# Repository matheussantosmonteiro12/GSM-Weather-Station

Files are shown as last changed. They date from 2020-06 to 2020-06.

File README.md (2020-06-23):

# GSM-Weather-Station
Estação meteorológica que mede microclimas e envia esses dados via GSM. 
## Resumo: 
Este projeto propõe uma rede de monitoramento climático utilizando estações meteorológicas autonomas, que transmitem os dados coletados atraves rede GSM (Global System for Mobile Communications), para um Middleware IoT, responsável por fazer a persistencia dos dados e fornecer informações sobre o clima para as diversas aplicações, focadas em ajudar os usuários no planejamento da rotina diária.
## Programas Necessários:
-**IDE arduino**, https://www.arduino.cc/en/Main/Software.

-**Cura Software** ou **Slic3r**.

## Companentes necessários:
- 1 Módulo A6 Gsm/Gprs.

- 1 Arduino mega.

- 1 Módulo sensor de chuva.

- 1 Módulo sensor de luminosidade de luz LDR.

- 1 Sensor de umidade e temperatura DHT 11.

- 1 Atiny 85.

- 1 Regulador de Tensão 7805 5V.

- 1 Relé nec 5V.

- 1 Módulo carregador tp4056.

- 3 Painel Placa Solar 12v 1.50w Carregador Ecologico 9v.

- 1 Modulo Conversor Tensão Dc/dc Step Up.

## Arquitetura da solução proposta:
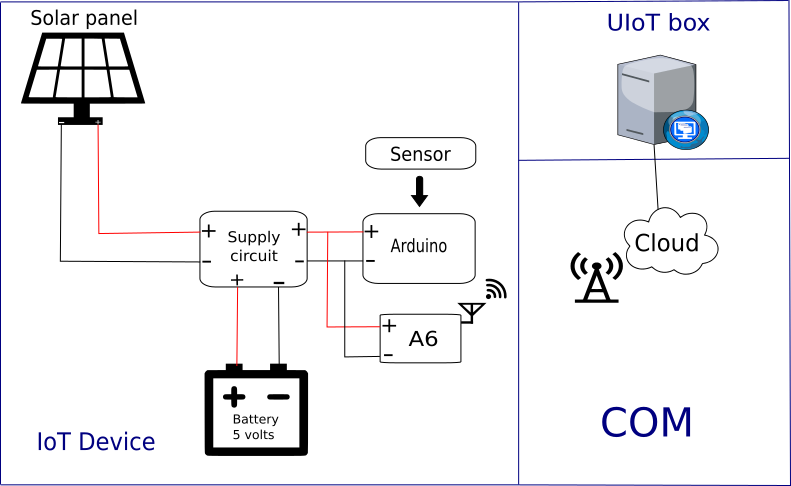
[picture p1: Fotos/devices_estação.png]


## Circuito de alimentação:
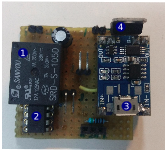
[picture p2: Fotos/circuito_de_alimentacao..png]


**1) Relé, 2) Microcontrolador, 3) Carregador de bateria, 4) Regulador de tensão.**

## Circuito principal:
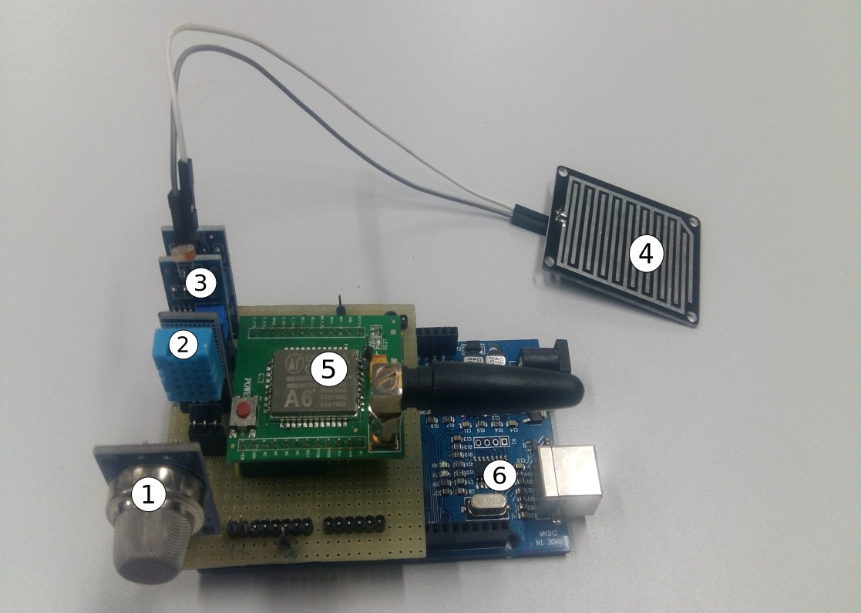
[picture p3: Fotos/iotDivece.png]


**1) Sensor de gás, 2) Sensor de temperatura e umidade, 3) Sensor de luminosidade, 4) Sensor de chuva, 5) A6 GSM/GPRS, 6) Microcontrolador.**

## Versão final da estação:
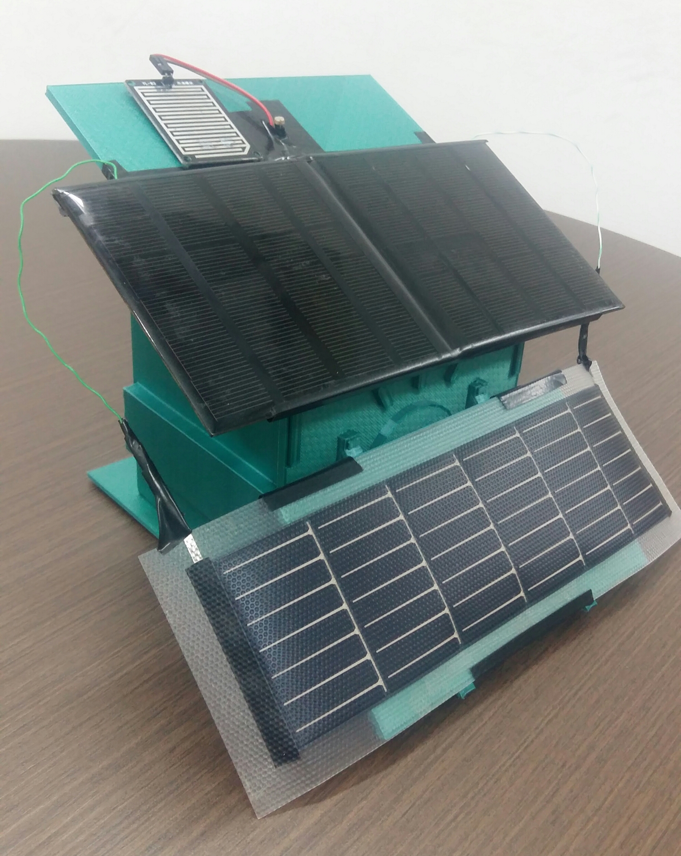
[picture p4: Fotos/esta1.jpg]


#### Link do Artigo sobre esse projeto:
https://ieeexplore.ieee.org/abstract/document/8896242

#### OBS:
Para qualquer outras duvidas me mande um email no matheus.monteiro@uiot.org.

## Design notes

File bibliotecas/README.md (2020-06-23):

# UIoT Devices

This librarys aim is to enable users to create *Clients* and *Services* that follow UIoT's Ontology of sending and managing message flows in Arduino devices.

All the protocols included as a means of communication in this library follow the same principles:

 1. Create a *Device*
 2. Create a *Service*
 3. Send *Data*

<!-- The documentation of the Ontology followed by this library can be found at @@link-ontologia -->

The supported protocols by supported devices are displayed in the following table.

<table>
<tr>
    <th>Device</th>
    <th>Protocol</th>
    <th>Example</th>
  </tr>
  <tr>
    <td rowspan = 1 ><a href="https://github.com/uiot/client_libraries/tree/master/UIoTDevices">Arduino</a></td>
    <td>HTTP</td>
      <td><a href="https://github.com/uiot/client_libraries/tree/master/UIoTDevices/examples/httpExampleArduino">httpExampleArduino</a></td>
  </tr>
  <tr>
    <td rowspan = 1><a href="https://github.com/uiot/client_libraries/tree/master/UIoTDevices_esp8266">Esp8266</a></td>
    <td>HTTP</td>
      <td><a href="https://github.com/uiot/client_libraries/tree/master/UIoTDevices_esp8266/examples/httpExampleEsp8266">httpExampleEsp8266</a></td>
  </tr>
  </table>

Examples can also be found in the table above, with a full code that uses the corresponding library. All examples can be found int the examples folder.

# Arduino

# HTTP

  The HTTP library depends on the following libraries:

  * EEPROM.h
  * Ethernet.h

  So, they must be installed in the users environment. The Ethernet library was used and tested to the WizNet 5100 Ethernet Shield.

  ## Creating a Device

  A *Device* is an object of the UHttp class that represents the hardware whose means of communication protocol is the HTTP.

  To create a device using UHttp library you must create an instance of it, initialize it and, finally, set a server to send data to, as demonstrated below

  ```c++
  UHttp device;
  (...)
  device.init();
  device.set_server(SERVER_STRING);
  ```

## Creating a Service

  A *Service* in an object of the Service class that represents a task witch a *Device* has.

  To create a service using UHttp library you must create an instance of it and set a value from the [*UHttp.create_service*](#create_service) method as demonstrated below

  ```c++
  Service service1;
  (...)
  device.create_service(number, name, unit, numeric, parameter);
  ```

## Sending Data

  To send data to the specified server, you must use the [*UHttp.send_data*](#send_data) method as demonstrated below

  ```c++
    device.send_data(service1, ptr , tam, 0);
  ```

## Methods

### set_server

```c++
void UHttp::set_server(const char *server)
```

| Parameter | Type | Description | Obligatory |
|-|-|-|-|
| server | char* | array of characters that contains the servers domain or IP[1] | :heavy_check_mark:

[1]The servers port is set to 8000 byt default, to change it you must define your a variable called *HTTP_PORT* in your code.

### create_service

```c++
int BaseProtocol::create_service(int number, const char *name, String unit, bool numeric, String parameter)
```

| Parameter | Type | Description | Obligatory |
|-|-|-|-|
| number | int | Number to be attributed to the Service object that is beeing created | :heavy_check_mark:
| name | char* | Array of characters that mounts the name of the Service object that is beein created| :heavy_check_mark:
| unit | String | String that contais the unit of the value that is produced by the Service object that is beeing createed | :heavy_check_mark:
| numeric | bool | Value that indicates if the data produced by the service is of a numeric type or not | :heavy_check_mark:
| parameter | String | Value that indicates the parameters of the Service object that is beeing created | :heavy_check_mark:

### send_data

```c++
    bool BaseProtocol::send_data(Service service, float *data, int array_size, int sensitive=0)
```

| Parameter | Type | Description | Obligatory |
|-|-|-|-|
| service | Service | Service object with the *services* characteristics | :heavy_check_mark:
| data | float* | Array of float values corresponding to the data produced from the service| :heavy_check_mark:
| array_size | int | number of values in the data array | :heavy_check_mark:
| sensitive | int | value that indicates if the data is sensitive or not, that is, if the data must bypass the gateways buffer (default value is 0 - not sensitive)| :x:

```c++
    bool BaseProtocol::send_data(Service service, char *char_data, int sensitive=0)
```

| Parameter | Type | Description | Obligatory |
|-|-|-|-|
| service | Service | Service object with the *services* characteristics | :heavy_check_mark:
| char_data | float* | Array of characters with the value corresponding to the data produced from the service| :heavy_check_mark:
| sensitive | int | value that indicates if the data is sensitive or not, that is, if the data must bypass the gateways buffer (default value is 0 - not sensitive)| :x:

<!-- TODO# Serial -->

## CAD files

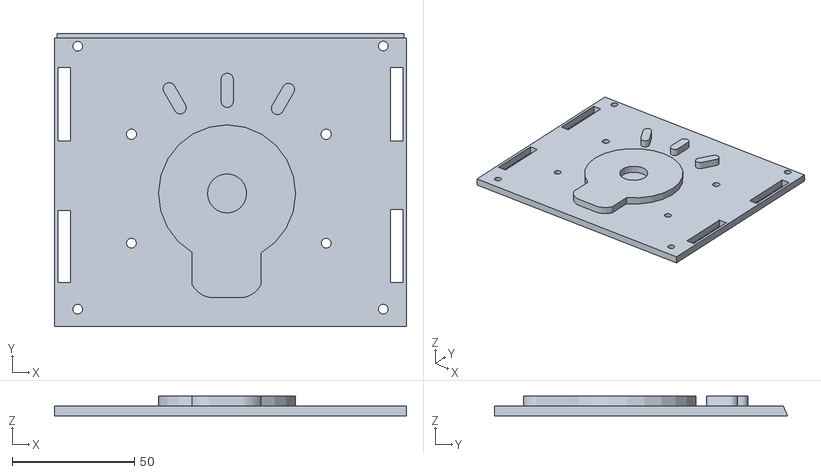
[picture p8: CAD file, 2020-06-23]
Modelagem da caixa em 3D/2.Tampa_do_lado_fixed.stl
144.0 x 120.0 x 8.00

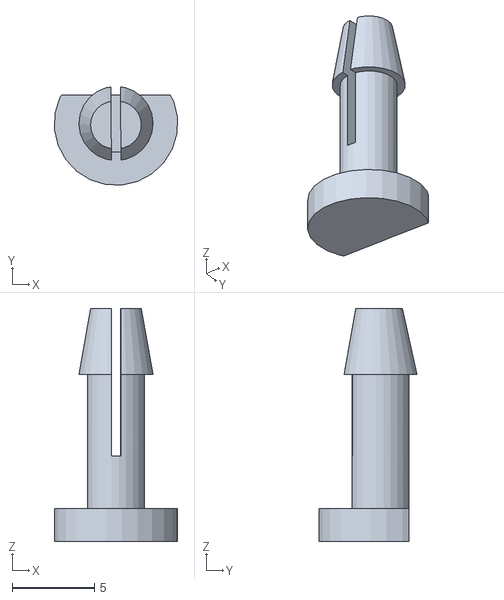
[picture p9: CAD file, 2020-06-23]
Modelagem da caixa em 3D/6.Clip_8x4_mm_uiot_fixed.stl
7.46 x 5.95 x 14.1

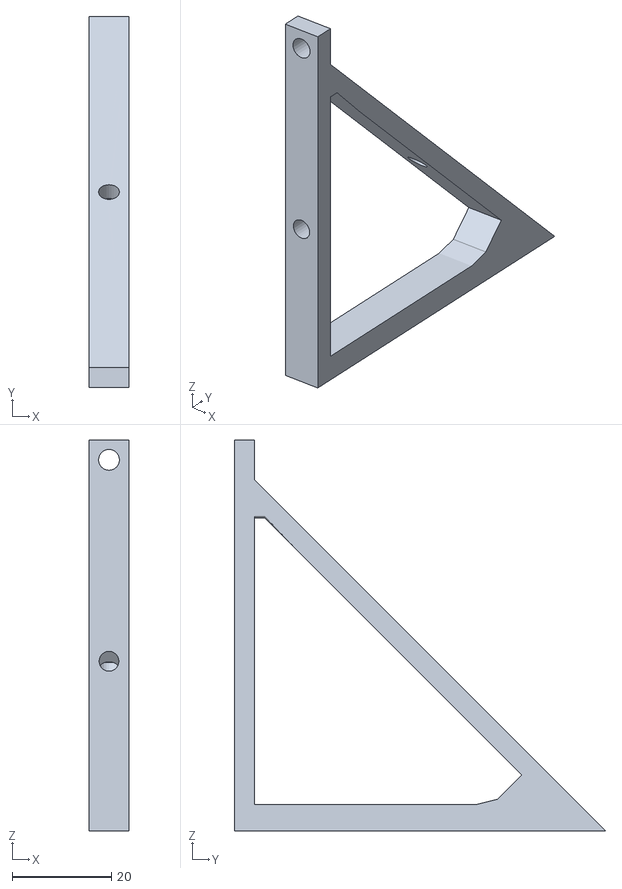
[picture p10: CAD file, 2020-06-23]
Modelagem da caixa em 3D/4.Suporte_para_placa_solar_fixed.stl
8.00 x 74.7 x 78.7

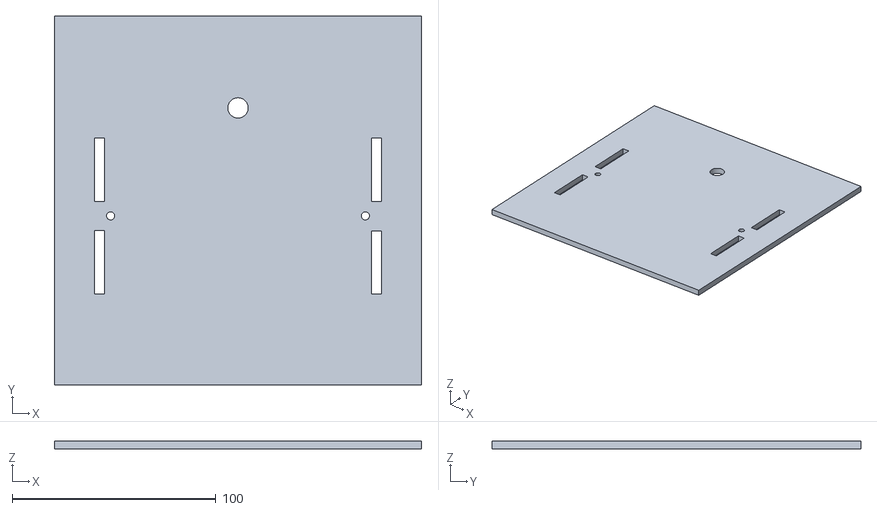
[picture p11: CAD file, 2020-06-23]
Modelagem da caixa em 3D/3.Tampa de cima_fixed.stl
180.0 x 180.8 x 4.00

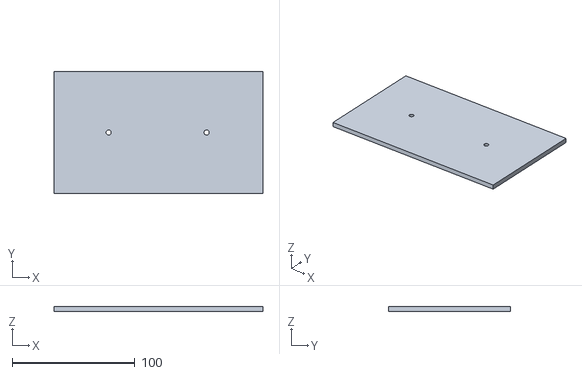
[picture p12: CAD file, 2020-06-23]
Modelagem da caixa em 3D/5.Suporte_para_placa_solar_mesa_fixed.stl
170.0 x 99.0 x 4.00

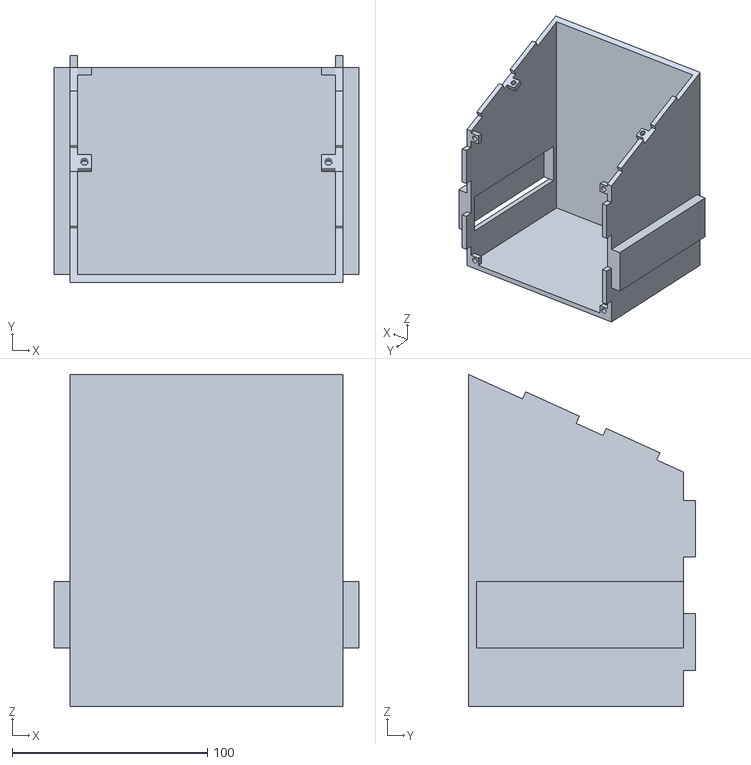
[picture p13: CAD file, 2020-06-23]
Modelagem da caixa em 3D/1.Caixa do tempo 4mm_fixed.stl
156.0 x 116.0 x 170.0

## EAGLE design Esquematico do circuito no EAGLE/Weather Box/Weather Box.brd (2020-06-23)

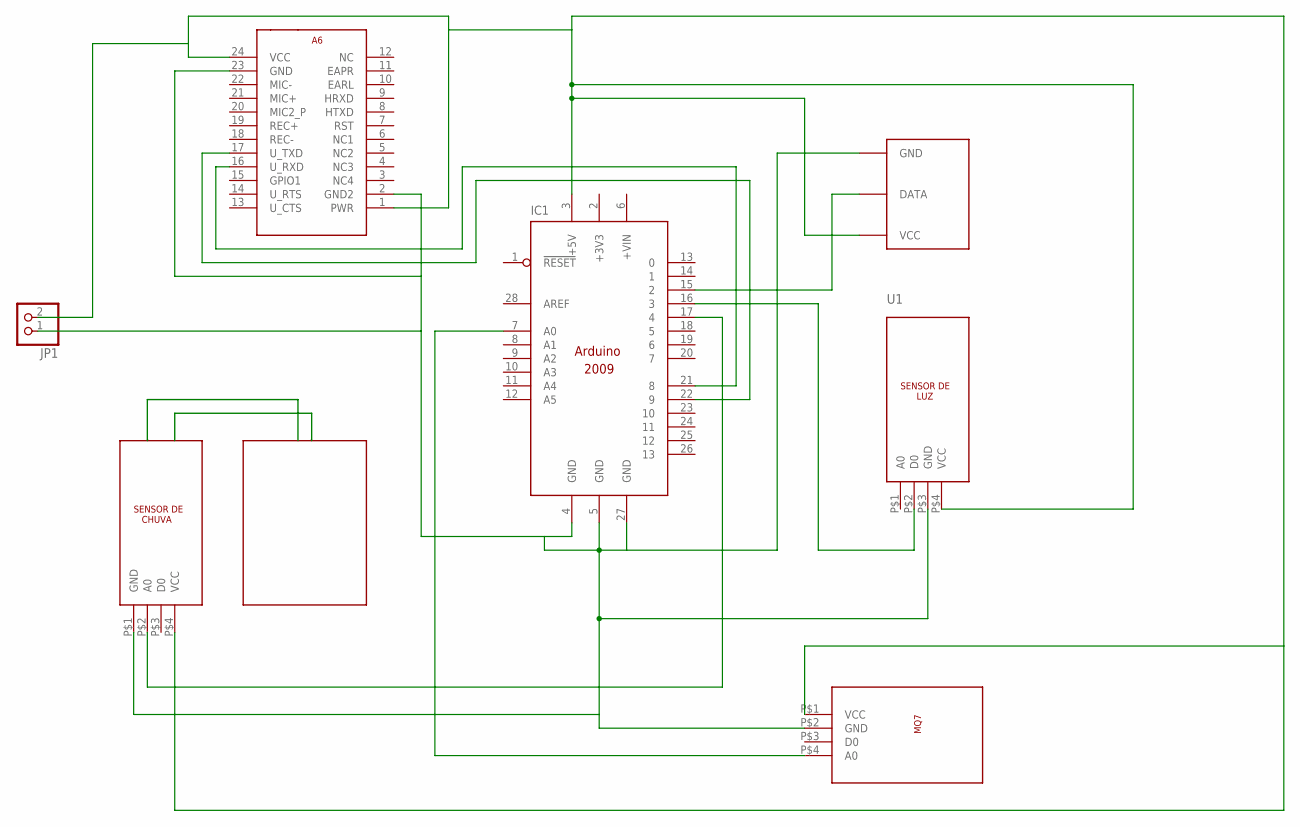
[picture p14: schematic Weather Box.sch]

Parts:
IC1: ARDUINO2009_10; ARDUINO2009
JP1: PINHD-1X2; 1X02
SHT1: DHT11DHT11-UPRIGHT; DHT11-UP
U1: LDRLDR-UPRIGHT; LDR-UP
U2: A6GPRS; A6_MODULE_V3
U3: RAINLDR-UPRIGHT; RAIN-UP
U4: MQ7MQ7-UPRIGHT; MQ7-UP

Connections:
+3V3: IC1.2 (+3V3)
unnamed: IC1.7 (A0), U4.P$4 (A0)
unnamed: IC1.3 (+5V), JP1.2, SHT1.P$1 (VCC), U1.P$4 (VCC), U2.1 (PWR), U2.24 (VCC), U3.P$4 (VCC), U4.P$1 (VCC)
unnamed: IC1.22 (9), U2.17 (U_TXD)
unnamed: IC1.21 (8), U2.16 (U_RXD)
unnamed: IC1.4 (GND), IC1.5 (GND), IC1.27 (GND), JP1.1, SHT1.P$4 (GND), U1.P$3 (GND), U2.2 (GND2), U2.23 (GND), U3.P$1 (GND), U4.P$2 (GND)
unnamed: IC1.17 (4), U3.P$2 (A0)
unnamed: IC1.16 (3), U1.P$2 (D0)
unnamed: IC1.15 (2), SHT1.P$3 (DATA)

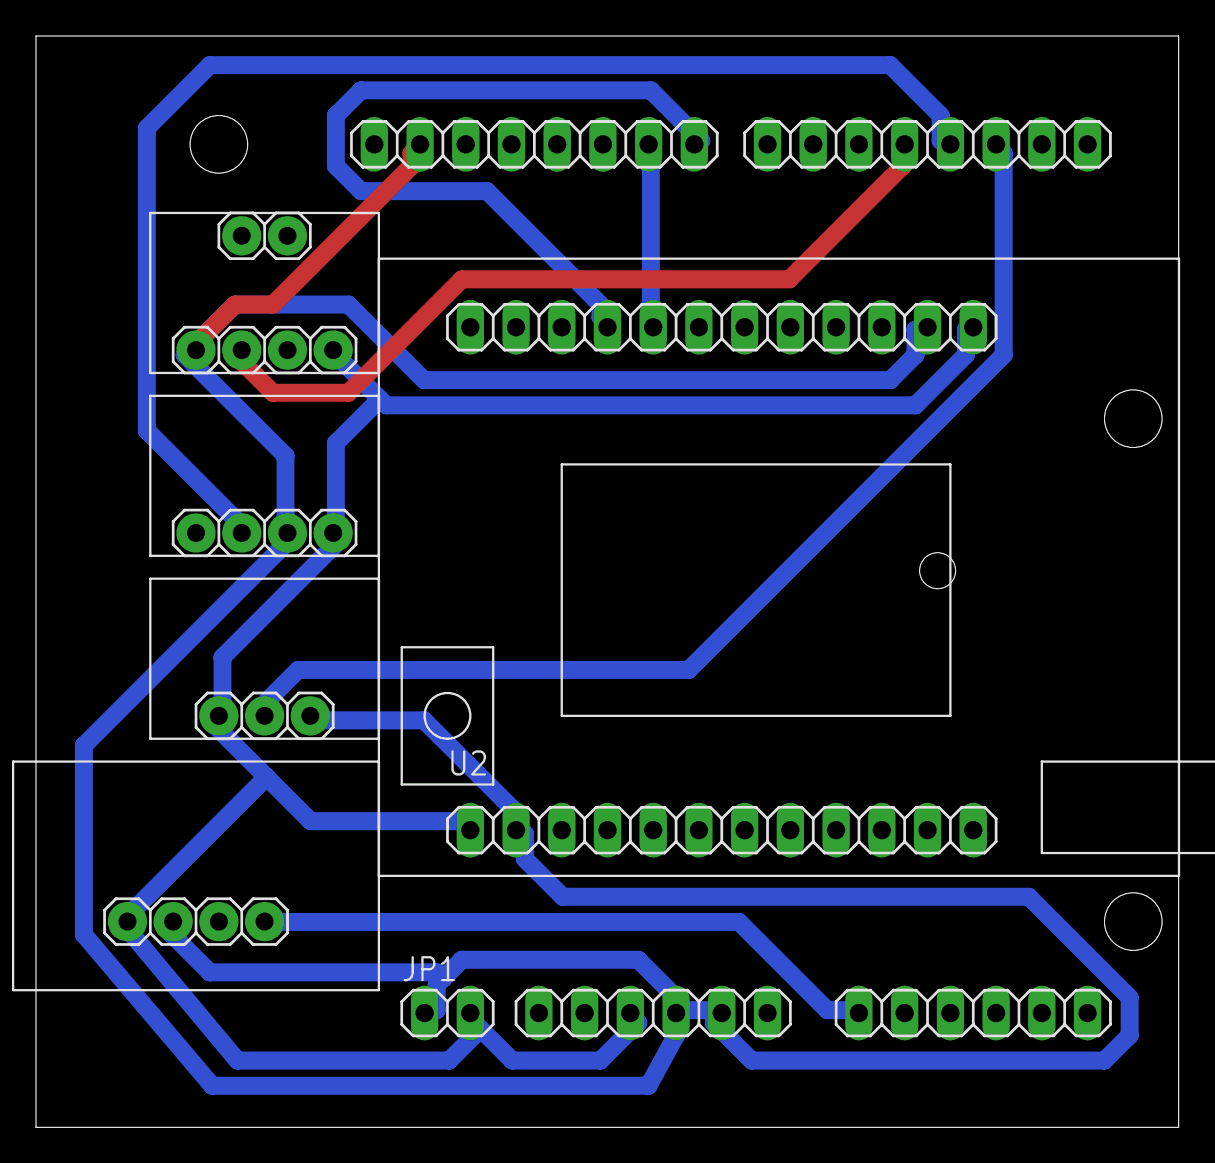
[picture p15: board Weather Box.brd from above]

Board: 2 copper layers, 63.5 x 60.6 mm, 7 parts (0 on the bottom side), 8 nets.

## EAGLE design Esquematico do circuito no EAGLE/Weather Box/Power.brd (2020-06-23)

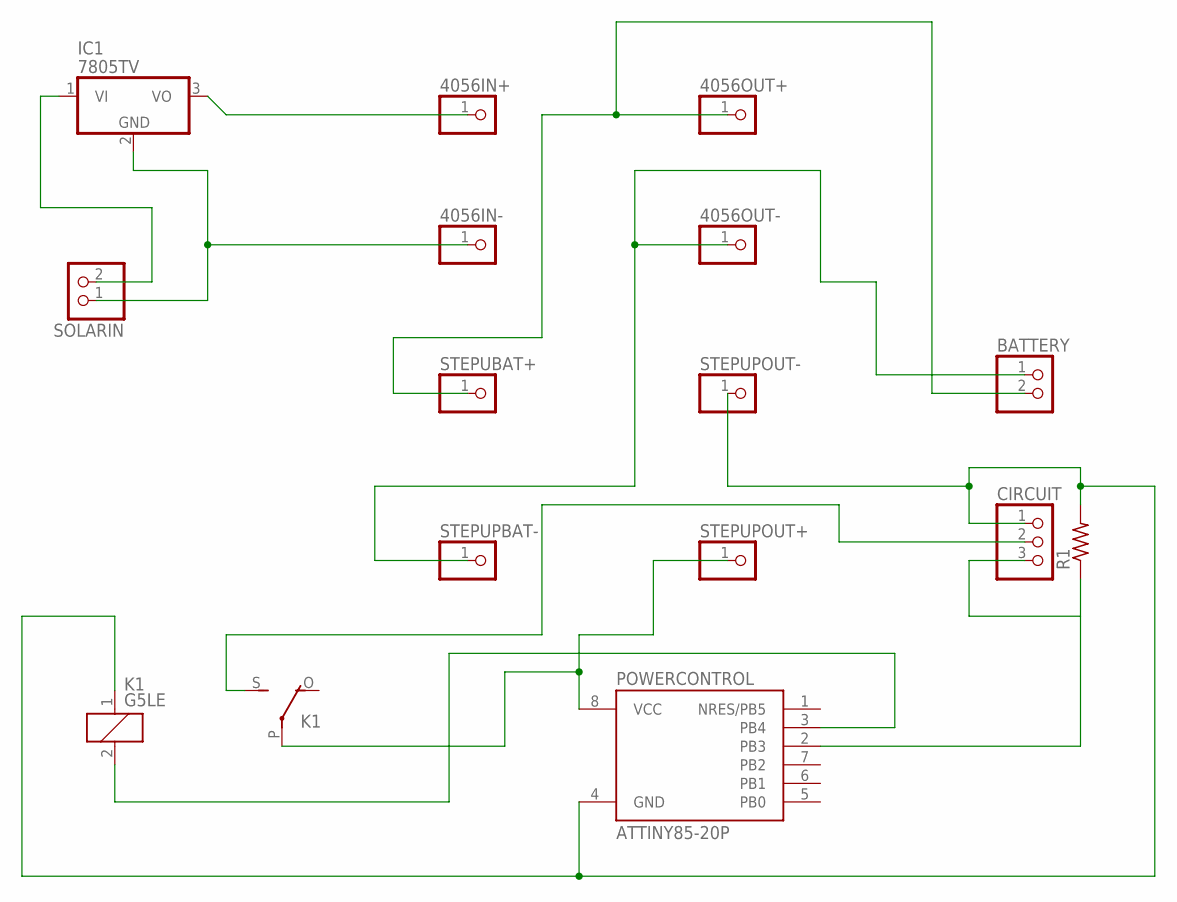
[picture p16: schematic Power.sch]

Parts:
4056IN+, 4056IN-, 4056OUT+, 4056OUT-: PINHD-1X1; 1X01
BATTERY: PINHD-1X2; 1X02
CIRCUIT: PINHD-1X3; 1X03
IC1: 7805TV; TO220V
K1: G5LE
POWERCONTROL: ATTINY85-20P; PDIP08_300MIL
R1: R-US_0204/7; 0204/7
SOLARIN: PINHD-1X2; 1X02
STEPUBAT+: PINHD-1X1; 1X01
STEPUPBAT-: PINHD-1X1; 1X01
STEPUPOUT+: PINHD-1X1; 1X01
STEPUPOUT-: PINHD-1X1; 1X01

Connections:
unnamed: IC1.1 (VI), SOLARIN.2
unnamed: 4056IN-.1, IC1.2 (GND), SOLARIN.1
unnamed: 4056IN+.1, IC1.3 (VO)
unnamed: 4056OUT+.1, BATTERY.2, STEPUBAT+.1
unnamed: K1.2, POWERCONTROL.3 (PB4)
unnamed: K1.P, POWERCONTROL.8 (VCC), STEPUPOUT+.1
unnamed: CIRCUIT.2, K1.S
unnamed: CIRCUIT.1, K1.1, POWERCONTROL.4 (GND), R1.2, STEPUPOUT-.1
unnamed: CIRCUIT.3, POWERCONTROL.2 (PB3), R1.1
unnamed: 4056OUT-.1, BATTERY.1, STEPUPBAT-.1

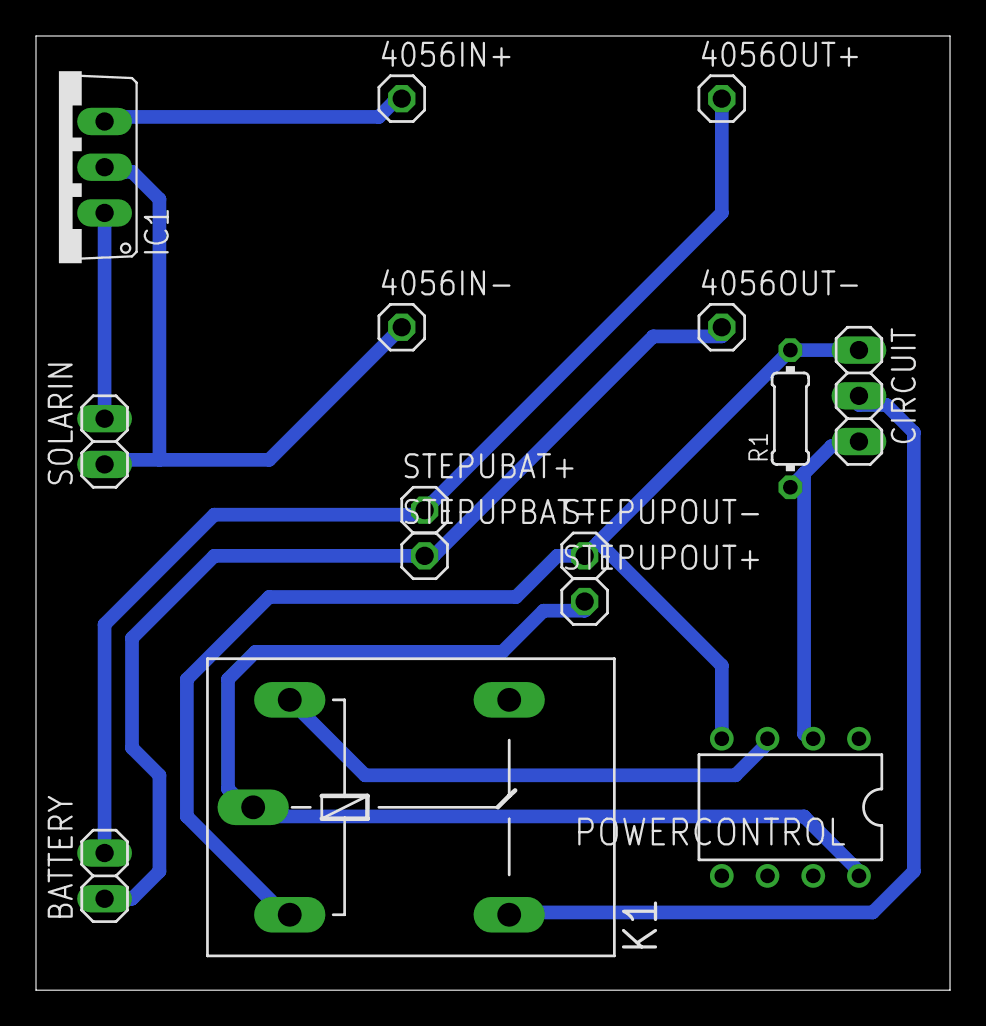
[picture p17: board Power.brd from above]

Board: 2 copper layers, 50.8 x 53.0 mm, 15 parts (0 on the bottom side), 10 nets.

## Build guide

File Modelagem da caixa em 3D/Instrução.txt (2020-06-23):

24 Clipe 8x4 mm
2 Suportes para placa solar
1 caixa do tempo
1 tampa do lado 
1 tampa de cima 
1 mesa para o suporte da placa solar

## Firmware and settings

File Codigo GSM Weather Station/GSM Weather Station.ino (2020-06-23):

//pin2=temperatura e umidade
//pin3=luz 
//pin4=Chuva
#include <LiquidCrystal.h>
#include <a7gprs.h>
#include "DHT.h"
#define DHTTYPE DHT11
#define DHTPIN 2 
const int sensor_ldr = 3;

a7gprs device;
int service1,service2,service3,service4,service5;
float* lat_long;
String s="1";
float pino_d = 4; 
DHT dht(DHTPIN, DHTTYPE);


void setup() { 
  Serial.setTimeout(200);
  Serial.begin(38400);
   pinMode(7, OUTPUT);
  digitalWrite(7, LOW);
  device.set_server("uiot-gateway.herokuapp.com");
    service1 = device.create_service(0, "getTemperatura", "ºC", 1, "weather_box");
    service2 = device.create_service(1, "getHumidity", "%", 1, "weather_box");
    service3 = device.create_service(2, "getLuz", "%", 1, "weather_box");
    service4 = device.create_service(3, "getrain", "%", 1, "weather_box");
    service5 = device.create_service(4, "getCO", "ppm", 1, "weather_box");
    lat_long = (float*)malloc(2*sizeof(float));
    
    device.init();
    dht.begin();
    pinMode(pino_d, INPUT);
}

void loop() {
  bool r;
//  digitalWrite(7, LOW);
  do{
    s=read_Temperature();
    r=device.send_data(service1,s.c_str(),0);
    if(!r) {
      device.connect();
    }
  }while(!r);
  do{
    s=read_Humidity();
    r=device.send_data(service2,s.c_str(),0);
    if(!r) {
      device.connect();
    }
  }while(!r);
  do{
    s=read_light();
    r=device.send_data(service3,s.c_str(),0);
    if(!r) {
      device.connect();
    }
  }while(!r);
  do{
    s=read_rain();
    r=device.send_data(service4,s.c_str(),0);
    if(!r) {
      device.connect();
    }
  }while(!r);
  do{
    s=read_CO();
    r=device.send_data(service5,s.c_str(),0);
    if(!r) {
      device.connect();
    }
  }while(!r);
  digitalWrite(7, HIGH);
  delay(1000);
}



//--------------------------------------------------------------------------------------------------------------------------------------------------
String read_Temperature(){
    String temperatura = "";
    float t = dht.readTemperature();
    if (isnan(t)) {
//    Serial.println("Failed to read from DHT sensor!");
    return temperatura;
    }
    temperatura = String(t);
    //Serial.println(floatToString(temperatura, t, 2));
    return temperatura;
  }
//------------------------------------------------------------------------------------------------------------------------------------------------
String read_Humidity(){
  String Humidity = "";
  float h = dht.readHumidity();
  if (isnan(h)) {
//    Serial.println("Failed to read from DHT sensor!");
    return Humidity;
    }
    Humidity=String(h);
    //Serial.println(floatToString(Humidity, h, 2));
    return Humidity;
  }
 //---------------------------------------------------------------------------------------------------------------------------------------------------------
//Sensor de luz
String read_light(){
  float leitura=analogRead(sensor_ldr);  
  return String((1023 - leitura)*0.1);
}
  //--------------------------------------------------------------------------------------------------------------------------------------------------
//sensor de chuva e neve 
  
String read_rain(){
  float leitura = analogRead(pino_d);
  float porcentagem ;
  porcentagem = (1000 - leitura)*0.1;
  if(porcentagem <= 0){
    return "0";
  }else{
    return String(porcentagem);
  }
}

//--------------------------------------------------------------------
//sensor de co em ppm, Mq7 pin A0

String read_CO(){
  float RS_gas = 0;
  float ratio = 0;
  float sensorValue = 0;
  float sensor_volt = 0;
  float R0 = 7200.0;
  sensorValue = analogRead(A0);
  sensor_volt = sensorValue/1024*5.0;
  RS_gas = (5.0-sensor_volt)/sensor_volt;
  ratio = RS_gas/R0; //Replace R0 with the value found using the sketch above
  return String(pow((1538.46 * ratio),-1.709));
} 

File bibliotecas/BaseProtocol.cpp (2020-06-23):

#include "BaseProtocol.h"

int BaseProtocol::create_service(int number, const char *name, String unit, bool numeric, String parameter){
  this->service[number] = Service(number, name, unit, numeric, parameter);
  return this->service[number].number;
}

bool BaseProtocol::send_data(int service, float *data, int array_size, int sensitive=0) {
  char * char_data = float_to_char(data, array_size);
	this->DEVICE_REGISTERED = (!this->DEVICE_REGISTERED)? this->register_all(service, char_data, sensitive) : this->register_service_data(service, char_data, sensitive);
  free(char_data);
  return this->DEVICE_REGISTERED;
}

bool BaseProtocol::send_data(int service, char *char_data, int sensitive=0) {
	this->DEVICE_REGISTERED = (!this->DEVICE_REGISTERED)? this->register_all(service, char_data, sensitive) : this->register_service_data(service, char_data, sensitive);
  return this->DEVICE_REGISTERED;
}

void BaseProtocol::set_mac(String new_mac){
  this->mac = new_mac;
}
void BaseProtocol::device_identificator(){
  int address = 0;
  int bytes[8];

  if (EEPROM.read(0) != 'U' || EEPROM.read(1) != 'T'){
    EEPROM.write(0, 'U');
    EEPROM.write(1, 'T');

    int iterator = 0xFF;
    for (int i = 0; i < 8; i++){
      int a = millis();
      int b = rand() % 123 + 1;
      int unique = a * b;
      bytes[i] = unique & iterator;
      EEPROM.write(i + 2,bytes[i]);
    }
  } else{
    for (int i = 0; i < 8; i++){
      bytes[i] = EEPROM.read(i+2);
   }
  }
  this->mac_byte[4] = bytes[0];
  this->mac_byte[5] = bytes[1];

  for (int i = 0; i < 6; i++){
    this->chipset_byte[i] = bytes[i+2];
  }

  for(int i = 0; i < 6; i++){
    byte b = this->chipset_byte[i];
    this->chipset += this->nibble_to_char((b & 0xF0)>>4);
    this->chipset += this->nibble_to_char(b & 0xF);
    this->chipset += ":";
  }
  this->chipset.remove(this->chipset.length()-1,1);

  for(int i = 0; i < 6; i++){
    byte b = this->mac_byte[i];
    this->mac += this->nibble_to_char((b & 0xF0)>>4);
    this->mac += this->nibble_to_char(b & 0xF);
    this->mac += ":";
  }
  this->mac.remove(this->mac.length()-1,1);
  //Serial.print("MAC: ");
  //Serial.println(this->mac);
}

bool BaseProtocol::register_all(int service, char *data, int sensitive){
	return this->register_device() && this->register_service_data(service, data, sensitive);
}

bool BaseProtocol::register_service_data(int service,  char* data, int sensitive){
   //Serial.println(this->service[service].registered);
  if (this->service[service].registered){
    if(this->register_data(service, data, sensitive)){
      return true;
    }
    else{
      this->service[service].registered = false;
      return false;
    }
  }
  else{
  //Serial.println("Else");
    if(this->register_service(service) && this->register_data(service, data, sensitive)){
      //Serial.println("AKI");
      //Serial.println(this->service[0].registered);
      this->service[service].registered = true;
      //Serial.println(this->service[service].registered);
      return true;
    }
    else{
      //Serial.println("OIE");
      this->service[service].registered = false;
      return false;
    }
  }
}


char *BaseProtocol::make_client_data(char* json){
  json = (char*)malloc(2*sizeof(char));
  json[0] = '{';
  json[1] = '\0';
  json = this->append_json(json, "name", this->name.c_str(),0);
  json = this->append_json(json, "chipset", this->chipset.c_str(),0);
  json = this->append_json(json, "mac", this->mac.c_str(),0);
  json = this->append_json(json, "serial", this->serial.c_str(),0);
  json = this->append_json(json, "processor", this->processor.c_str(),0);
  json = this->append_json(json, "channel", this->channel.c_str(),0);
  json[strlen(json)-1] = '}';
  return json;
}


char *BaseProtocol::make_service_data(Service service, char* json){

  json = (char*)malloc(2*sizeof(char));
  json[0] = '{';
  json[1] = '\0';
  json  = this->append_json(json, "name", service.name,0);
  json = this->append_json(json, "chipset", this->chipset.c_str(),0);
  json = this->append_json(json, "mac", this->mac.c_str(),0);
  json = this->append_json(json, "parameter", service.parameter.c_str(),0);
  json = this->append_json(json, "number", String(service.number).c_str(), 1);
  json = this->append_json(json, "unit", service.unit.c_str(),0);
  json = this->append_json(json, "numeric", String(service.numeric).c_str(),1);
  json[strlen(json)-1] = '}';
  //Serial.println(json);
  return json;
}

char *BaseProtocol::make_raw_data(Service s, char *data, int sensitive, char* json){
  //Serial.println("AQUI");
  //Serial.println(data);
  json = (char*)malloc(2*sizeof(char));
  json[0] = '{';
  json[1] = '\0';
  json = this->append_json(json, "chipset", this->chipset.c_str(), 0);
  json = this->append_json(json, "mac", this->mac.c_str(), 0);
  json = this->append_json(json, "sensitive", String(sensitive).c_str(),1);
  json = this->append_json(json, "serviceNumber", String(s.number).c_str(),1);
  json = this->append_json(json, "values", data, s.numeric);
  json[strlen(json)-1] = '}';
  return json;
}


char* BaseProtocol::append_json(char *json, const char* key, const char* value, int numeric){
  if(key == "values" && !numeric){
    strcat(json, "\"");
    strcat(json, key);
    strcat(json, "\":[\"");
    strcat(json, value);
    strcat(json, "\"],");
    json[strlen(json)] = '\0';
  }else if(key == "values" && numeric){
    json = (char*) realloc (json, (strlen(key) + strlen(value) + 7 + strlen(json)) * sizeof(char)); // 5 because "" and : and ,
    strcat(json, "\"");
    strcat(json, key);
    strcat(json, "\":[");
    strcat(json, value);
    strcat(json, "],");
    json[strlen(json)] = '\0';
  }else if(key != "values" && !numeric){
    json = (char*) realloc (json, (strlen(key) + strlen(value) + 7 + strlen(json)) * sizeof(char)); // 5 because "" and : and ,
    strcat(json, "\"");
    strcat(json, key);
    strcat(json, "\":\"");
    strcat(json, value);
    strcat(json, "\",");
    json[strlen(json)] = '\0';
  }else if(key != "values" && numeric){
    json = (char*) realloc (json, (strlen(key) + strlen(value) + 5 + strlen(json)) * sizeof(char)); // 5 because "" and : and ,
    strcat(json, "\"");
    strcat(json, key);
    strcat(json, "\":");
    strcat(json, value);
    strcat(json, ",");
    json[strlen(json)] = '\0';
  }
  return json;
}

char* BaseProtocol::float_to_char(float* float_array, int array_size){
  char *values;
  values = (char*)malloc(2*sizeof(char));
  // values[0] = '[';
  values[0] = '\0';
  String b;
  int contador = 2;
  for(int i = 0; i < array_size; i++){
    // Serial.println(dtostrf(float_array[i], 10, 3, b));
    b = String(float_array[i]);
    contador += b.length() + 1;
    values = (char*) realloc (values, (contador ) * sizeof(char));
    strcat(values, b.c_str());
    strcat(values, ",");
    // Serial.print("values: ");
    // Serial.println(values);
  }
  values[contador-2] = '\0';

  // strcat(values, "]");

  return values;
}
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

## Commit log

2020-06-23 Modelo em 3D
    [1.Caixa do tempo 4mm_fixed.stl, 2.Tampa_do_lado_fixed.stl, 3.Tampa de cima_fixed.stl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]
2020-06-23 Instrução
    Instruções para impressão
